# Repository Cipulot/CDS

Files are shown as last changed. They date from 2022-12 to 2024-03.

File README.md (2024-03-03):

# CDS

Replacement PCB fro the CDS Technology keyboard (CDS-G5CSKB, Topre HiPro)/

## Introduction

This project is a continuation of my development of open source EC boards.

The CDS Technology keyboard layout is the sole layout option available:

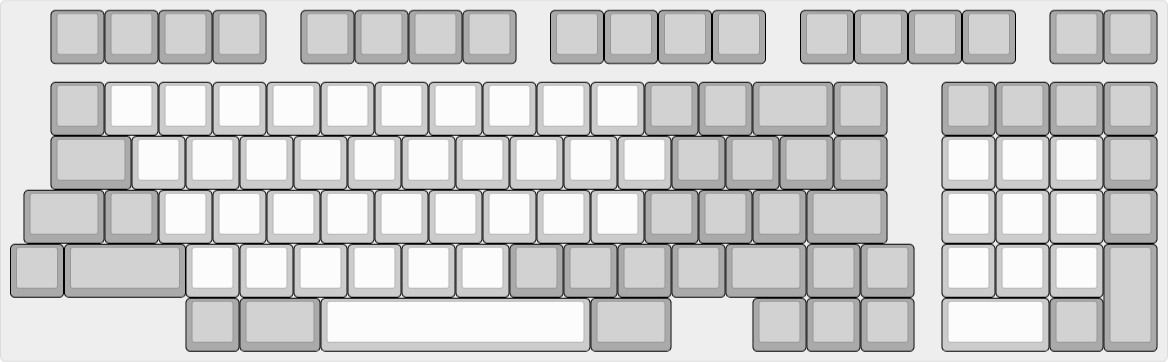
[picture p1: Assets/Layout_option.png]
Layout option


## Technical information

- Layout size: board specific
- Compatible switches: EC switches (Topre and NIZ)
- Microcontroller: STM32F401
- Connector: USB-C
- Firmware compatibility: QMK (with VIA/VIAL support)
- Protection hardware (present on both the mainboard and both controller versions):
  - Fused
  - ESD protection

## Renders and Prototypes

### Render

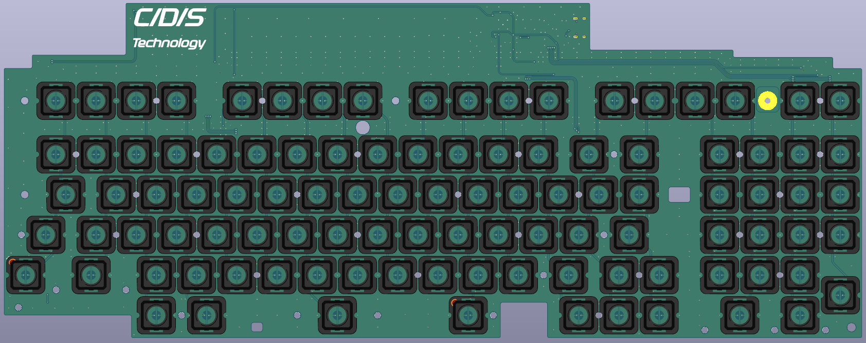
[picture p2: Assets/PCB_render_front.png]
PCB Front Render


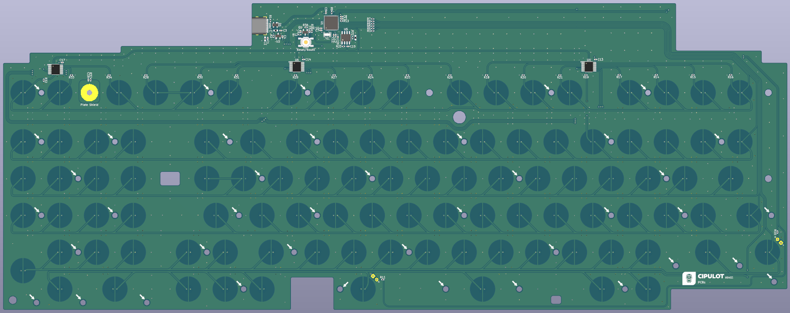
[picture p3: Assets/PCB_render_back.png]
PCB Back Render


### Prototypes

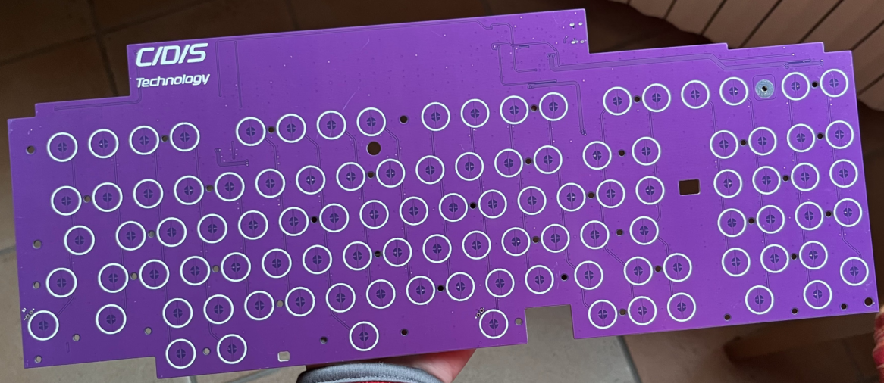
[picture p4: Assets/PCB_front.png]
PCB Front


## Revisions and relative features

### Rev1.0

This revision implements all the main features of the mainboard mentioned in the specifications.

#### Reset | DFU

**RESET**: Shortly press the `Reset/BOOT0` button.

**DFU**: Press and hold the `Reset/BOOT0`.

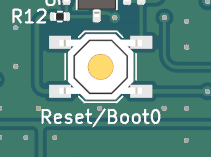
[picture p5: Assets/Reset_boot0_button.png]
Boot0 pins


## Copyright notice

This project is not endorse nor sponsored in any way by Topre Corporation or CDS Technology.

## License

<br />This work is licensed under a <a rel="license" href="http://creativecommons.org/licenses/by-nc-sa/4.0/">Creative Commons Attribution-NonCommercial-ShareAlike 4.0 International License</a>.

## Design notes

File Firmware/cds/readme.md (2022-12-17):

# CDS

Replacement PCB for the CDS Topre keyboard.

* Keyboard Maintainer: [cipulot](https://github.com/cipulot)
* Hardware Supported: CDS Replacement PCB
* Hardware Availability: TBD

Make example for this keyboard (after setting up your build environment):

    make cds:default
    make cds:vial

Flashing example for this keyboard:

    make cds:default:flash
    make cds:vial:flash

See the [build environment setup](https://docs.qmk.fm/#/getting_started_build_tools) and the [make instructions](https://docs.qmk.fm/#/getting_started_make_guide) for more information. Brand new to QMK? Start with our [Complete Newbs Guide](https://docs.qmk.fm/#/newbs).

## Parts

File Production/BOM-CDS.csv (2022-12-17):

Comment | Designator | Footprint | LCSC
1k | R23 | R_0402_1005Metric | C11702
STM32F401CBUx | U1 | QFN-48-1EP_7x7mm_P0.5mm_EP5.6x5.6mm | C118825
OPA350 | U5 | SOIC-8_3.9x4.9mm_P1.27mm | C13388
220p | C15 | C_0402_1005Metric | C1530
HRO-TYPE-C-31-M-12 | USB1 | HRO-TYPE-C-31-M-12-Assembly | C165948
4.7u | C2,C5 | C_0402_1005Metric | C23733
100 | R10,R11,R3,R4,R5,R6,R7,R8 | R_0402_1005Metric | C25076
330 | R37 | R_0402_1005Metric | C25104
100k | R14,R15,R16,R17,R18,R19,R20,R21,R22,R24,R25,R26,R27,R28,R29,R30,R31,R32,R33,R34,R36,R9 | R_0402_1005Metric | C25741
10k | R12,R13,R35 | R_0402_1005Metric | C25744
5.1k | R1,R2 | R_0402_1005Metric | C25905
PRTR5V0U2X | D1 | SOT-143 | C2827688
100n | C1,C10,C11,C13,C14,C16,C17,C18,C7,C8,C9 | C_0402_1005Metric | C307331
Magic Switch | SW1 | SW_SPST_TL3342 | C318884
1u | C12,C3,C4,C6 | C_0402_1005Metric | C52923
XC6206PxxxMR | U2 | SOT-23 | C5446
74HC4051 | U4,U6,U7 | TSSOP16 | C5645
500mA | F1 | Fuse_0603_1608Metric | C720073
2N7002 | Q1 | SOT-23 | C8545
220 @ 100MHz, 2A | L1 | L_0603_1608Metric | C85832
8 MHz | Y1 | Resonator_SMD_Murata_CSTxExxV-3Pin_3.0x1.1mm | C907975

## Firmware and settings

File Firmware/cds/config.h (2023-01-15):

/* Copyright 2023 Cipulot
 *
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
 * You should have received a copy of the GNU General Public License
 * along with this program.  If not, see <http://www.gnu.org/licenses/>.
 */

#pragma once

#include "config_common.h"

/* key matrix size */
#define MATRIX_ROWS 6
#define MATRIX_COLS 19

/* Custom matrix pins and port select array */
#define MATRIX_ROW_PINS \
    { A4, A5, A6, A7, B1, B0 }
#define MATRIX_COL_CHANNELS \
    { 2, 1, 0, 3, 5, 7, 6, 4 }
#define MUX_SEL_PINS \
    { B5, B6, B7 }

/* Hardware peripherals pins */
#define APLEX_EN_PIN_0 B14
#define APLEX_EN_PIN_1 A0
#define APLEX_EN_PIN_2 B4
#define DISCHARGE_PIN A3
#define ANALOG_PORT A2

/* LED Pins*/
#define LED_PIN_1 B12
#define LED_PIN_2 B13

/* COL2ROW, ROW2COL */
#define DIODE_DIRECTION COL2ROW

/* Debounce reduces chatter (unintended double-presses) - set 0 if debouncing is not needed */
//#define DEBOUNCE 5

/* Mechanical locking support. Use KC_LCAP, KC_LNUM or KC_LSCR instead in keymap */
#define LOCKING_SUPPORT_ENABLE

/* Locking resynchronize hack */
#define LOCKING_RESYNC_ENABLE

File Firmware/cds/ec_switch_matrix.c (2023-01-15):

/* Copyright 2023 Cipulot
 *
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
 * You should have received a copy of the GNU General Public License
 * along with this program.  If not, see <http://www.gnu.org/licenses/>.
 */

#include "ec_switch_matrix.h"

#include "quantum.h"
#include "analog.h"
#include "atomic_util.h"
#include "print.h"

#define WAIT_DISCHARGE()
#define WAIT_CHARGE()

/* Pin and port array */
const uint32_t row_pins[]     = MATRIX_ROW_PINS;
const uint8_t  col_channels[] = MATRIX_COL_CHANNELS;
const uint32_t mux_sel_pins[] = MUX_SEL_PINS;

static ecsm_config_t config;
static uint16_t      ecsm_sw_value[MATRIX_ROWS][MATRIX_COLS];

static adc_mux adcMux;

static inline void discharge_capacitor(void) {
    writePinLow(DISCHARGE_PIN);
}
static inline void charge_capacitor(uint8_t row) {
    writePinHigh(DISCHARGE_PIN);
    writePinHigh(row_pins[row]);
}

static inline void clear_all_row_pins(void) {
    for (int row = 0; row < MATRIX_ROWS; row++) {
        writePinLow(row_pins[row]);
    }
}

static inline void init_mux_sel(void) {
    for (int idx = 0; idx < 3; idx++) {
        setPinOutput(mux_sel_pins[idx]);
    }
}

static inline void select_mux(uint8_t col) {
    uint8_t ch = col_channels[col];
    writePin(mux_sel_pins[0], ch & 1);
    writePin(mux_sel_pins[1], ch & 2);
    writePin(mux_sel_pins[2], ch & 4);
}

static inline void init_row(void) {
    for (int idx = 0; idx < MATRIX_ROWS; idx++) {
        setPinOutput(row_pins[idx]);
        writePinLow(row_pins[idx]);
    }
}

/* Initialize the peripherals pins */
int ecsm_init(ecsm_config_t const* const ecsm_config) {
    // Save config
    config = *ecsm_config;

    palSetLineMode(ANALOG_PORT, PAL_MODE_INPUT_ANALOG);
    adcMux = pinToMux(ANALOG_PORT);

    // Initialize discharge pin as discharge mode
    writePinLow(DISCHARGE_PIN);
    setPinOutputOpenDrain(DISCHARGE_PIN);

    // Initialize drive lines
    init_row();

    // Initialize multiplexer select pin
    init_mux_sel();

    // Enable AMUX
    setPinOutput(APLEX_EN_PIN_0);
    writePinLow(APLEX_EN_PIN_0);
    setPinOutput(APLEX_EN_PIN_1);
    writePinLow(APLEX_EN_PIN_1);
    setPinOutput(APLEX_EN_PIN_2);
    writePinLow(APLEX_EN_PIN_2);

    return 0;
}

// Read the capacitive sensor value
static uint16_t ecsm_readkey_raw(uint8_t channel, uint8_t row, uint8_t col) {
    uint16_t sw_value = 0;

    // Select the multiplexer
    if (channel == 0) {
        writePinHigh(APLEX_EN_PIN_0);
        select_mux(col);
        writePinLow(APLEX_EN_PIN_0);
    } else if (channel == 1) {
        writePinHigh(APLEX_EN_PIN_1);
        select_mux(col);
        writePinLow(APLEX_EN_PIN_1);
    } else {
        writePinHigh(APLEX_EN_PIN_2);
        select_mux(col);
        writePinLow(APLEX_EN_PIN_2);
    }

    // Set strobe pins to low state
    writePinLow(row_pins[row]);

    ATOMIC_BLOCK_FORCEON {
        // Set the row pin to high state and have capacitor charge
        charge_capacitor(row);

        WAIT_CHARGE();
        sw_value = adc_read(adcMux);
    }

    // Discharge peak hold capacitor
    discharge_capacitor();
    WAIT_DISCHARGE();

    return sw_value;
}

// Update press/release state of key at (row, col)
static bool ecsm_update_key(matrix_row_t* current_row, uint8_t row, uint8_t col, uint16_t sw_value) {
    bool current_state = (*current_row >> col) & 1;

    // press to release
    if (current_state && sw_value < config.low_threshold_matrix[row][col]) {
        *current_row &= ~(1 << col);
        return true;
    }

    // release to press
    if ((!current_state) && sw_value > config.high_threshold_matrix[row][col]) {
        *current_row |= (1 << col);
        return true;
    }

    return false;
}

// Scan key values and update matrix state
bool ecsm_matrix_scan(matrix_row_t current_matrix[]) {
    bool updated = false;

    // Disable AMUX of channel 1 and 2
    writePinHigh(APLEX_EN_PIN_1);
    writePinHigh(APLEX_EN_PIN_2);
    for (int col = 0; col < sizeof(col_channels); col++) {
        for (int row = 0; row < MATRIX_ROWS; row++) {
            ecsm_sw_value[row][col] = ecsm_readkey_raw(0, row, col);
            updated |= ecsm_update_key(&current_matrix[row], row, col, ecsm_sw_value[row][col]);
        }
    }

    // Disable AMUX of channel 0 and 2
    writePinHigh(APLEX_EN_PIN_0);
    writePinHigh(APLEX_EN_PIN_2);
    for (int col = 0; col < sizeof(col_channels); col++) {
        for (int row = 0; row < MATRIX_ROWS; row++) {
            ecsm_sw_value[row][col + 8] = ecsm_readkey_raw(1, row, col);
            updated |= ecsm_update_key(&current_matrix[row], row, col + 8, ecsm_sw_value[row][col + 8]);
        }
    }

    // Disable AMUX of channel 0 and 1
    writePinHigh(APLEX_EN_PIN_0);
    writePinHigh(APLEX_EN_PIN_1);
    for (int col = 0; col < (sizeof(col_channels) - 5); col++) {
        for (int row = 0; row < MATRIX_ROWS; row++) {
            ecsm_sw_value[row][col + 16] = ecsm_readkey_raw(2, row, col);
            updated |= ecsm_update_key(&current_matrix[row], row, col + 16, ecsm_sw_value[row][col + 16]);
        }
    }
    return updated;
}

// Debug print key values
void ecsm_print_matrix(void) {
    for (int row = 0; row < MATRIX_ROWS; row++) {
        for (int col = 0; col < MATRIX_COLS; col++) {
            uprintf("%4d", ecsm_sw_value[row][col]);
            if (col < (MATRIX_COLS - 1)) {
                print(",");
            }
        }
        print("\n");
    }
    print("\n\n");
}

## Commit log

2022-12-17 PCB project dump
    [CDS.kicad_sch, analog.kicad_sch, matrix.kicad_sch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]
2022-12-17 Production files dump
    [BOM-CDS.csv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]
2023-01-08 Update for 3d models
    [CDS.kicad_sch, matrix.kicad_sch]
2023-11-17 Updated sheets
    [CDS.kicad_sch, analog.kicad_sch, matrix.kicad_sch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]
2024-03-03 Update
    Updated the License for the project and relative details.
    [CDS.kicad_sch, analog.kicad_sch, matrix.kicad_sch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]

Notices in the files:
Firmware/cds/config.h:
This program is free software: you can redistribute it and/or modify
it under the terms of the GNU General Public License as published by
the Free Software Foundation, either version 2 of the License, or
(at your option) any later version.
